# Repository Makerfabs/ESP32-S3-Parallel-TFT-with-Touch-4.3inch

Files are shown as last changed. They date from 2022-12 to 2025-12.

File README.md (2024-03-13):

# Makerfabs ESP32-S3 Parallel TFT with Touch 4.3inch

```c++
/*
Version:        V1.1
Author:            Vincent
Create Date:    2022/12/29
Note:
    2023/4/15 V1.2: Update V2.0 hardware.
    2023/1/10 V1.1: Update code to match the V1.3 hardware.
*/
```

[TOC]

# Makerfabs

[Makerfabs home page](https://www.makerfabs.com/)

[Makerfabs Wiki](https://wiki.makerfabs.com/)

# Makerfabs ESP32-S3 Parallel TFT with Touch 4.3inch

## Intruduce

Product Link ：[ESP32-S3 Parallel TFT with Touch 4.3"](https://www.makerfabs.com/esp32-s3-parallel-tft-with-touch-4-3-inch.html)

Wiki Link : [ESP32-S3 Parallel 4.3 TFT with Touch](http://wiki.makerfabs.com/ESP32_S3_Parallel_4.3_TFT_with_Touch.html)

This ESP32 4.3 inch IPS display could be an ideal displayer& controller for IoT applications. Its high lightness IPS display with a resolution of 800*480 makes the display effect beautiful, together with 5 points capacitive touch, great for applications such as home automation; There onboard SD card and RTC, to make it possible to record/play filed data. Also, there 2 Mabee/ Grove connectors, so the users can connect kinds of sensors to this board, to create personal prototype projects instantly.

The ESP32-S3 has WiFi& Bluetooth 5.0, and 8M PSRAM ESP32-S3 is used in this product, with 16M flash, to make it competent for more advanced applications.

## Feature

- Controller: ESP32-S3-WROOM-1, PCB Antenna, 16MB Flash, 8MB PSRAM, ESP32-S3-WROOM-1-N16R8
- On Board RTC
- Wireless: Wifi& Bluetooth 5.0
- LCD: 4.3 inch High Lightness IPS
- FPS: >30
- Resolution: 800*480
- LCD interface: RGB 565
- Touch Panel: 5 Points Touch, Capacitive
- Touch Panel Driver: GT911
- USB: Dual USB Type-C(one for USB-to-UART and one for native USB)
- USB to UART Chip: CP2104
- Power Supply: USB Type-C 5.0V(4.0V~5.25V)
- Button: Flash button and reset button
- Mabee interface: 1*I2C;1*GPIO
- MicroSD: Yes
- Arduino support: Yes
- Type-C Power Delivery: Not Supported
- Operation temperature: -40℃ to +85℃

## Version Attention

### V2.0

The codes has not been modified yet, please wait a little.

Still working...

| | V2.0 | V1.3 |
| --- | ---- | ---- |
| LCD_BLK | NULL | 2 |
| I2S_DIN | 19 | NULL |
| I2S_BCLK  | 20 | NULL |
| I2S_LRCLK | 2 | NULL |
| | | |

Now the screen has no backlight PWM adjustment function, the pins are assigned to I2S. By default, the hardware backlight is always on.

### V1.3

V1.3 switches the touch screen RST and INT pins compared to V1.1 hardware.

```c++
// Hardware V1.3
#define TOUCH_GT911_SCL 18
#define TOUCH_GT911_SDA 17
#define TOUCH_GT911_INT -1
#define TOUCH_GT911_RST 38
```

### V1.1

If the silk screen on the back of your hardware is V1.1, follow the Branch V1.1 procedure.

# Code

## Complier Option

- Install board : ESP32 (Version 2.0.4)
- Install libraries：

library

- Use type-c use cable connect USB-TTL to PC.
- Select "ESP32-S3 DEV Module"
- Select PSRAM "OPI PSRAM"

"mf_Lvgl" library is modified from Lvgl library (version 8.3.2). 

Please unzip "lib/mf_Lvgl.zip" and copy to arduino library directory.

## Factory test program

examples\esp32s3_4.3_tft_fw_test

You can run this file test if you feel that your hardware is not working properly. You need to copy the images from the Images folder to the included TF card.

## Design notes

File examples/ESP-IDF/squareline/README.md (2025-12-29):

## LVGL design with SquareLine Studio

1. Click on Squareline to log in to your account, or click on "Sign up" if you don't have one.

2. Create a project.

2. Design Interface.

3. Export the UI code and select a folder to save it to.

   

## Code Upload with IDF

- Clone the [ESP32-S3-Parallel-TFT-with-Touch-4.3inch](https://github.com/Makerfabs/ESP32-S3-Parallel-TFT-with-Touch-4.3inch/tree/main) repository and configure it according to the documentation.

  ```bash
  git clone https://github.com/Makerfabs/ESP32-S3-Parallel-TFT-with-Touch-4.3inch.git
  ```

- Copy the previously exported `ui` folder to the `components` directory and modify `ui/CmakeLists.txt`.

  > This example uses an interface I designed as an illustration.

  ```cmake
  idf_component_register(
      SRCS 
          "ui.c"
          "ui_helpers.c"
          "components/ui_comp.c"
          "components/ui_comp_card.c"
          "components/ui_comp_hook.c"
          "screens/ui_Screen1.c"
          "images/ui_img_wifi_png.c"
          "images/ui_img_home_png.c"
          "images/ui_img_1292609536.c"
          "images/ui_img_image_png.c"
          "images/ui_img_music_png.c"
          "images/ui_img_bell_png.c"
          "images/ui_img_settings_png.c"
      INCLUDE_DIRS 
          "."
          "components" 
          "screens"
          "images"
      REQUIRES 
          lvgl
  )
  ```

- Include the UI header file in `main/firmware/template.c`.

  ```c
  #include "ui.h"
  ```

  Modify the `template_lvgl_demos_test` function.

  ```c
  void template_lvgl_demos_test()
  {
      lvgl_port_lock(0);
  
      // lv_demo_widgets();
      
      // ui_init_styles();
      // create_main_ui();
  
      ui_init();
  
      lvgl_port_unlock();
  }
  ```

- Modify `main/release/4-3-unknown-gt911/release.c`

  ```c
  static void release_task(void *arg)
  {
      // extern void template_image_switch_lvgl(const char *path);
      // template_image_switch_lvgl("/sdcard/images");
  
      extern void template_lvgl_demos_test();
      template_lvgl_demos_test();
  
      // extern void template_dht11_test();
      // template_dht11_test();
  
      // extern void template_mpu6050_test();
      // template_mpu6050_test();
      
      vTaskDelete(NULL);
  }
  ```

After compiling and flashing the code at this stage, you should be able to see the interface designed in **Squareline Studio** on the screen.  Next, we will connect the **MPU6050** to the development board and display the sensor data on the designed interface.

- Add the **mpu6050** component. Modify `main/idf_components.yml` and add the following at the end:

  ```yml
  k0i05/esp_mpu6050: 1.2.7
  ```

- Modify `main/boards/board.h` and add the following at the end:

  ```c
  extern i2c_master_bus_handle_t _i2c_bus;
  ```

- The **MPU6050** sensor is connected to the **J2** interface on the development board. Modify the `main/firmware/template.c` file and add the `template_mpu6050_test` function.

  ```c
  void template_mpu6050_test()
  {
      mpu6050_config_t dev_cfg          = I2C_MPU6050_CONFIG_DEFAULT;
      dev_cfg.accel_full_scale_range    = MPU6050_ACCEL_FS_RANGE_2G;
      mpu6050_handle_t dev_hdl;
      //
      // init device
      mpu6050_init(_i2c_bus, &dev_cfg, &dev_hdl);
  
      uint8_t                                 sample_rate_divider_reg;
      mpu6050_config_register_t               config_reg;
      mpu6050_gyro_config_register_t          gyro_config_reg;
      mpu6050_accel_config_register_t         accel_config_reg;
      mpu6050_interrupt_enable_register_t     irq_enable_reg;
      mpu6050_power_management1_register_t    power_management1_reg;
      mpu6050_power_management2_register_t    power_management2_reg;
      mpu6050_who_am_i_register_t             who_am_i_reg;
  
      /* attempt to read device sample rate divider register */
      mpu6050_get_sample_rate_divider_register(dev_hdl, &sample_rate_divider_reg);
  
      /* attempt to read device configuration register */
      mpu6050_get_config_register(dev_hdl, &config_reg);
  
      /* attempt to read device gyroscope configuration register */
      mpu6050_get_gyro_config_register(dev_hdl, &gyro_config_reg);
  
      /* attempt to read device accelerometer configuration register */
      mpu6050_get_accel_config_register(dev_hdl, &accel_config_reg);
  
      /* attempt to read device interrupt enable register */
      mpu6050_get_interrupt_enable_register(dev_hdl, &irq_enable_reg);
  
      /* attempt to read device power management 1 register */
      mpu6050_get_power_management1_register(dev_hdl, &power_management1_reg);
  
      /* attempt to read device power management 2 register */
      mpu6050_get_power_management2_register(dev_hdl, &power_management2_reg);
  
      /* attempt to read device who am i register */
      mpu6050_get_who_am_i_register(dev_hdl, &who_am_i_reg);
  
          // show registers
      ESP_LOGI(TAG, "Sample Rate Divider Register:         0x%02x (%s)", sample_rate_divider_reg, uint8_to_binary(sample_rate_divider_reg));
      ESP_LOGI(TAG, "Configuration Register:               0x%02x (%s)", config_reg.reg, uint8_to_binary(config_reg.reg));
      ESP_LOGI(TAG, "Gyroscope Configuration Register:     0x%02x (%s)", gyro_config_reg.reg, uint8_to_binary(gyro_config_reg.reg));
      ESP_LOGI(TAG, "Accelerometer Configuration Register: 0x%02x (%s)", accel_config_reg.reg, uint8_to_binary(accel_config_reg.reg));
      ESP_LOGI(TAG, "Interrupt Enable Register:            0x%02x (%s)", irq_enable_reg.reg, uint8_to_binary(irq_enable_reg.reg));
      ESP_LOGI(TAG, "Power Management 1 Register:          0x%02x (%s)", power_management1_reg.reg, uint8_to_binary(power_management1_reg.reg));
      ESP_LOGI(TAG, "Power Management 2 Register:          0x%02x (%s)", power_management2_reg.reg, uint8_to_binary(power_management2_reg.reg));
      ESP_LOGI(TAG, "Who am I Register:                    0x%02x (%s)", who_am_i_reg.reg, uint8_to_binary(who_am_i_reg.reg));
  
      while (1) {
          // handle sensor
          float temperature;
          mpu6050_gyro_data_axes_t gyro_data;
          mpu6050_accel_data_axes_t accel_data;
          esp_err_t result = mpu6050_get_motion(dev_hdl, &gyro_data, &accel_data, &temperature);
          if(result != ESP_OK) {
              ESP_LOGE(TAG, "mpu6050 device read failed (%s)", esp_err_to_name(result));
          } else {
              /* pitch and roll */
              float pitch = atanf(accel_data.x_axis / sqrtf(powf(accel_data.y_axis, 2.0f) + powf(accel_data.z_axis, 2.0f)));
              float roll  = atanf(accel_data.y_axis / sqrtf(powf(accel_data.x_axis, 2.0f) + powf(accel_data.z_axis, 2.0f)));
  
              // ESP_LOGI(TAG, "Accelerometer X-Axis: %fg", accel_data.x_axis);
              // ESP_LOGI(TAG, "Accelerometer Y-Axis: %fg", accel_data.y_axis);
              // ESP_LOGI(TAG, "Accelerometer Z-Axis: %fg", accel_data.z_axis);
              // ESP_LOGI(TAG, "Gyroscope X-Axis:     %f°/sec", gyro_data.x_axis);
              // ESP_LOGI(TAG, "Gyroscope Y-Axis:     %f°/sec", gyro_data.y_axis);
              // ESP_LOGI(TAG, "Gyroscope Z-Axis:     %f°/sec", gyro_data.z_axis);
              // ESP_LOGI(TAG, "Temperature:          %f°C", temperature);
              // ESP_LOGI(TAG, "Pitch Angle:          %f°", pitch);
              // ESP_LOGI(TAG, "Roll Angle:           %f°", roll);
  
              lvgl_port_lock(0);
              lv_obj_t * label_temp = ui_comp_get_child(ui_card, UI_COMP_CARD_LBLTEMP);
              lv_obj_t * label_accel_x = ui_comp_get_child(ui_card1, UI_COMP_CARD_LBLTEMP);
              lv_obj_t * label_accel_y = ui_comp_get_child(ui_card2, UI_COMP_CARD_LBLTEMP);
              lv_obj_t * label_accel_z = ui_comp_get_child(ui_card3, UI_COMP_CARD_LBLTEMP);
              lv_label_set_text_fmt(label_temp, "%d", (int)temperature);
              lv_label_set_text_fmt(label_accel_x, "%.2f", accel_data.x_axis);
              lv_label_set_text_fmt(label_accel_y, "%.2f", accel_data.y_axis);
              lv_label_set_text_fmt(label_accel_z, "%.2f", accel_data.z_axis);
              lvgl_port_unlock();

          }
          vTaskDelay(pdMS_TO_TICKS(1000));
      }
  }
  ```

- Modify `main/release/4-3-unknown-gt911/release.c`

  ```c
  static void release_task(void *arg)
  {
      // extern void template_image_switch_lvgl(const char *path);
      // template_image_switch_lvgl("/sdcard/images");
  
      extern void template_lvgl_demos_test();
      template_lvgl_demos_test();
  
      // extern void template_dht11_test();
      // template_dht11_test();
  
      extern void template_mpu6050_test();
      template_mpu6050_test();
      
      vTaskDelete(NULL);
  }
  ```

- The compilation, flashing, and execution results are as follows:

  VID20251229143917-ezgif.com-optimize

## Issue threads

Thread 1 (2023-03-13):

Arduino IDE 2.0.x

WanaGo, 2023-03-13:
Hi,
Have you attempted to get the LVGL Benchmark to compile and build using the Arduino 2.0.x IDE, rather than the 1.8.x IDE?

I cant get it to compile, just get weird errors which dont really say much.

```
Using library lvgl at version 8.3.2 in folder: C:\Users\wanago\Documents\Arduino\libraries\mf_Lvgl 
Using library GFX Library for Arduino at version 1.3.2 in folder: C:\Users\wanago\Documents\Arduino\libraries\GFX_Library_for_Arduino 
Using library SPI at version 2.0.0 in folder: C:\Users\wanago\AppData\Local\Arduino15\packages\esp32\hardware\esp32\2.0.7\libraries\SPI 
Using library Wire at version 2.0.0 in folder: C:\Users\wanago\AppData\Local\Arduino15\packages\esp32\hardware\esp32\2.0.7\libraries\Wire
```

```
c:/users/wanago/appdata/local/arduino15/packages/esp32/tools/xtensa-esp32s3-elf-gcc/esp-2021r2-patch5-8.4.0/bin/../lib/gcc/xtensa-esp32s3-elf/8.4.0/../../../../xtensa-esp32s3-elf/bin/ld.exe: C:\Users\wanago\AppData\Local\Temp\arduino\sketches\94789ED864D1E8CA07644E860EFAA592\sketch\objs.a(LvglBenchmark.ino.cpp.o):(.literal._Z5setupv+0x48): undefined reference to `lv_demo_benchmark'
c:/users/wanago/appdata/local/arduino15/packages/esp32/tools/xtensa-esp32s3-elf-gcc/esp-2021r2-patch5-8.4.0/bin/../lib/gcc/xtensa-esp32s3-elf/8.4.0/../../../../xtensa-esp32s3-elf/bin/ld.exe: C:\Users\wanago\AppData\Local\Temp\arduino\sketches\94789ED864D1E8CA07644E860EFAA592\sketch\objs.a(LvglBenchmark.ino.cpp.o): in function `setup()':
C:\Users\wanago\AppData\Local\Temp\.arduinoIDE-unsaved2023214-6888-1djzjol.71qj\LvglBenchmark/LvglBenchmark.ino:168: undefined reference to `lv_demo_benchmark'
collect2.exe: error: ld returned 1 exit status exit status 1 Compilation error: exit status 1
```

I see there is LVGL 8.3.5 available now, but given this uses a modified version of that 8.3.2 library I cannot upgrade to that to try it.

Any suggestions?

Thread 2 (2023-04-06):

hardware version 2.0

charnwooduk, 2023-04-06:
I received my board, but the silkscreen states it is version 2.0.

I appear to get the following error when using gfx library with the following settings : -

(using gfx version 1.3.1)

`
#include <Arduino_GFX_Library.h>
#define GFX_BL 2
#define TFT_BL GFX_BL
Arduino_ESP32RGBPanel *bus = new Arduino_ESP32RGBPanel(
    GFX_NOT_DEFINED /* CS */, GFX_NOT_DEFINED /* SCK */, GFX_NOT_DEFINED /* SDA */,
    40 /* DE */, 41 /* VSYNC */, 39 /* HSYNC */, 42 /* PCLK */,
    45 /* R0 */, 48 /* R1 */, 47 /* R2 */, 21 /* R3 */, 14 /* R4 */,
    5 /* G0 */, 6 /* G1 */, 7 /* G2 */, 15 /* G3 */, 16 /* G4 */, 4 /* G5 */,
    8 /* B0 */, 3 /* B1 */, 46 /* B2 */, 9 /* B3 */, 1 /* B4 */
);

// Uncomment for ST7262 IPS LCD 800x480
 Arduino_RPi_DPI_RGBPanel *gfx = new Arduino_RPi_DPI_RGBPanel(
   bus,
   800 /* width */, 0 /* hsync_polarity */, 8 /* hsync_front_porch */, 4 /* hsync_pulse_width */, 8 /* hsync_back_porch */,
   480 /* height */, 0 /* vsync_polarity */, 8 /* vsync_front_porch */, 4 /* vsync_pulse_width */, 8 /* vsync_back_porch */,
   1 /* pclk_active_neg */, 16000000 /* prefer_speed */, true /* auto_flush */);
`

Error: -
`
E (10) lcd_panel.rgb: esp_lcd_new_rgb_panel(151): no mem for frame buffer
ESP_ERROR_CHECK failed: esp_err_t 0x101 (ESP_ERR_NO_MEM) at 0x4037abb0
file: "C:\Users\Documents\Arduino\libraries\GFX_Library_for_Arduino\src\databus\Arduino_ESP32RGBPanel.cpp" line 252
func: uint16_t* Arduino_ESP32RGBPanel::getFrameBuffer(uint16_t, uint16_t, uint16_t, uint16_t, uint16_t, uint16_t, uint16_t, uint16_t, uint16_t, uint16_t, uint16_t, int32_t)
expression: esp_lcd_new_rgb_panel(_panel_config, &_panel_handle)
abort() was called at PC 0x4037abb3 on core 1
Backtrace: 0x40377862:0x3fcebc00 0x4037abbd:0x3fcebc20 0x40380ed5:0x3fcebc40 0x4037abb3:0x3fcebcc0 0x4200299b:0x3fcebce0 0x42002a9b:0x3fcebd40 0x42001928:0x3fcebd80 0x420046ca:0x3fcebda0
ELF file SHA256: 97d90b6539d5a233
Rebooting...
`

charnwooduk, 2023-04-07:
my mistake, fixed by following the instructions and setting OPI PSRAM .

Closed 2023-04-07.

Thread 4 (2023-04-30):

Clock example error - Hardware v2

ayouboss, 2023-04-30:
Compilation error: no matching function for call to 'Arduino_ESP32RGBPanel::Arduino_ESP32RGBPanel(int, int, int, int, int, int, int, int, int, int, int, int, int, int, int, int, int, int, int, int, int, int, int)'

zingo, 2023-05-04:
It could be that you picked up a the wrong version GFX Library for Arduino when I set up my project I had to lock it to 1.3.1
see:
https://github.com/zingo/CrazyCapyTime/blob/main/platformio.ini

ayouboss, 2023-05-04:
Thanks I will try that. I'm wondering if the same issue happens for LovyanGFX example: https://github.com/Makerfabs/ESP32-S3-Parallel-TFT-with-Touch-4.3inch/tree/main/examples/LovyanGFX_demo

When I upload the sketch I once get a full white screen, once full red, green, and blue screens. I've checked the Pinout in the header file and it seems to be correct. Comments even mention hardware v2.0.

Thanks in advance.

vibr77, 2023-05-20:
Same here none of the exemple are working....
black screen for clock, random for LovyanGFX...

seijikun, 2024-02-28:
I was able to get the clock example to work with `Arduino GFX 1.4.5` by replacing the [init code](https://github.com/Makerfabs/ESP32-S3-Parallel-TFT-with-Touch-4.3inch/blob/main/examples/Clock/Clock.ino#L10) with this:

```c++
Arduino_ESP32RGBPanel *bus = new Arduino_ESP32RGBPanel(
    40 /* DE */, 41 /* VSYNC */, 39 /* HSYNC */, 42 /* PCLK */,
    45 /* R0 */, 48 /* R1 */, 47 /* R2 */, 21 /* R3 */, 14 /* R4 */,
    5 /* G0 */, 6 /* G1 */, 7 /* G2 */, 15 /* G3 */, 16 /* G4 */, 4 /* G5 */,
    8 /* B0 */, 3 /* B1 */, 46 /* B2 */, 9 /* B3 */, 1 /* B4 */,
    0 /* hsync_polarity */, 8 /* hsync_front_porch */, 4 /* hsync_pulse_width */, 8 /* hsync_back_porch */,
    0 /* vsync_polarity */, 8 /* vsync_front_porch */, 4 /* vsync_pulse_width */, 8 /* vsync_back_porch */,
    1 /* pclk_active_neg */, 16000000 /* prefer_speed */, false, 0, 0
);
Arduino_RGB_Display* gfx = new Arduino_RGB_Display(800, 480, bus, 0, true, nullptr, GFX_NOT_DEFINED, nullptr, GFX_NOT_DEFINED, 0, 0, 0, 0);
```

sukesh-ak, 2024-02-29:
Here is a simple example for the device using `LovyanGFX` to get you started.
https://gist.github.com/sukesh-ak/c8325c4bb7ec3da40f24977526d513f8

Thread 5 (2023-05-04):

Add debugging to the guide

zingo, 2023-05-04:
It would be nice to add a guide on the README.md or other place on how to setup debugging via the onboard USB-JTAG stuff added in ESP32-S3 preferable with PlatformIO or any other means.  Been struggling with this for a few hours now without to much luck :)

GroundLevel1, 2023-05-05:
Hello
   Debugging tools are great in assistance of programing errors/issues,
they will always be welcomed.

Bryan H

On Thu, May 4, 2023 at 6:53 AM Zingo Andersen ***@***.***>
wrote:

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

zingo, 2023-06-01:
Experiemented some more it seem to show up on the USB-NATIVE connection if you press RST and FLASH at the same time.

`
zingo@zingodatan:~$ lsusb
...
Bus 002 Device 016: ID 303a:1001 Espressif USB JTAG/serial debug unit
...

zingo@zingodatan:~$ openocd -f board/esp32s3-builtin.cfg
Open On-Chip Debugger v0.11.0-esp32-20221026 (2022-10-26-14:47)
Licensed under GNU GPL v2
For bug reports, read
	http://openocd.org/doc/doxygen/bugs.html
Info : only one transport option; autoselect 'jtag'
Info : esp_usb_jtag: VID set to 0x303a and PID to 0x1001
Info : esp_usb_jtag: capabilities descriptor set to 0x2000
Warn : Transport "jtag" was already selected
Info : Listening on port 6666 for tcl connections
Info : Listening on port 4444 for telnet connections
Info : esp_usb_jtag: serial (34:85:18:98:52:3C)
Info : esp_usb_jtag: Device found. Base speed 40000KHz, div range 1 to 255
Info : clock speed 40000 kHz
Info : JTAG tap: esp32s3.cpu0 tap/device found: 0x120034e5 (mfg: 0x272 (Tensilica), part: 0x2003, ver: 0x1)
Info : JTAG tap: esp32s3.cpu1 tap/device found: 0x120034e5 (mfg: 0x272 (Tensilica), part: 0x2003, ver: 0x1)
Error: [esp32s3.cpu1] Unexpected OCD_ID = 00000000
Warn : target esp32s3.cpu1 examination failed
Info : starting gdb server for esp32s3.cpu0 on 3333
Info : Listening on port 3333 for gdb connections
Info : [esp32s3.cpu0] Debug controller was reset.
Info : [esp32s3.cpu0] Core was reset.
Info : [esp32s3.cpu0] Target halted, PC=0x40041A76, debug_reason=00000000
Info : [esp32s3.cpu0] Reset cause (1) - (Power on reset)
Error: [esp32s3.cpu1] Unexpected OCD_ID = 00000000
Error: [esp32s3.cpu1] Unexpected OCD_ID = 00000000
Error: [esp32s3.cpu1] Unexpected OCD_ID = 00000000
Error: [esp32s3.cpu1] Unexpected OCD_ID = 00000000
Error: [esp32s3.cpu1] Unexpected OCD_ID = 00000000

`

zingo, 2023-10-06:
started to play with this again, got some more to work:

1. Setup platformIO

`
platform = espressif32
board = esp32s3box
;board = esp32-s3-devkitc-1
board_build.filesystem = littlefs
;board_build.mcu = esp32s3
;board_build.f_cpu = 240000000L
framework = arduino
build_type = debug
debug_tool = esp-builtin
debug_init_break = tbreak initRaceDB
;upload_protocol = esp-builtin
upload_protocol = esptool
upload_speed = 921600
`

2. Experiemented some more it seem to show up on the USB-NATIVE connection if you press RST and FLASH at the same time.

3. in PlatformIO go to debug and select "PIO Debug"
check that it connects ok in "DEBUG CONSOLE"

4.  Press "RST" button, it seem to restart and contnue to the code and stop there

I had a breakpoint at start of setup() and it seem to get stuck there so this is not 100% working but seem to be roughtly the way to go :)

zingo, 2023-10-06:
It seem to work as it should with the settings above move code probed different deb boards by checking if there was a i2c touch controller on pin 19,20 this is the same pins as USB-Native uses so if this code had executed it didn't work so the error was on my side. It works with the the platformIO setting above it you don't touch pin 19,20 I close this.

Closed 2023-10-06.

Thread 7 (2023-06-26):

None of the Examples worked

RedStarITA, 2023-06-26:
I've tried every examples possible with my "ESP32-S3 Parallele TFT with Touch 4.3 V3.1", and it keeps saying:
"Compilation error: 'Arduino_ESP32RGBPanel' does not name a type; did you mean 'Arduino_ESP32SPI'?"

What's the problem? Is it about the libraries or what?

sukesh-ak, 2023-06-27:
@RedStarITA
You can try this sample and check
https://gist.github.com/sukesh-ak/c8325c4bb7ec3da40f24977526d513f8

barnbrooksystems, 2023-07-28:
Thanks @sukesh-ak at least your example works.  Rubbish support from the manufacturer

arcanine84, 2023-11-10:
Your example no longer works for the V3.1.

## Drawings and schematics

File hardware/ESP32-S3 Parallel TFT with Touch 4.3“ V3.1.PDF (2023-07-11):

POWER | USB to UART

# LCD

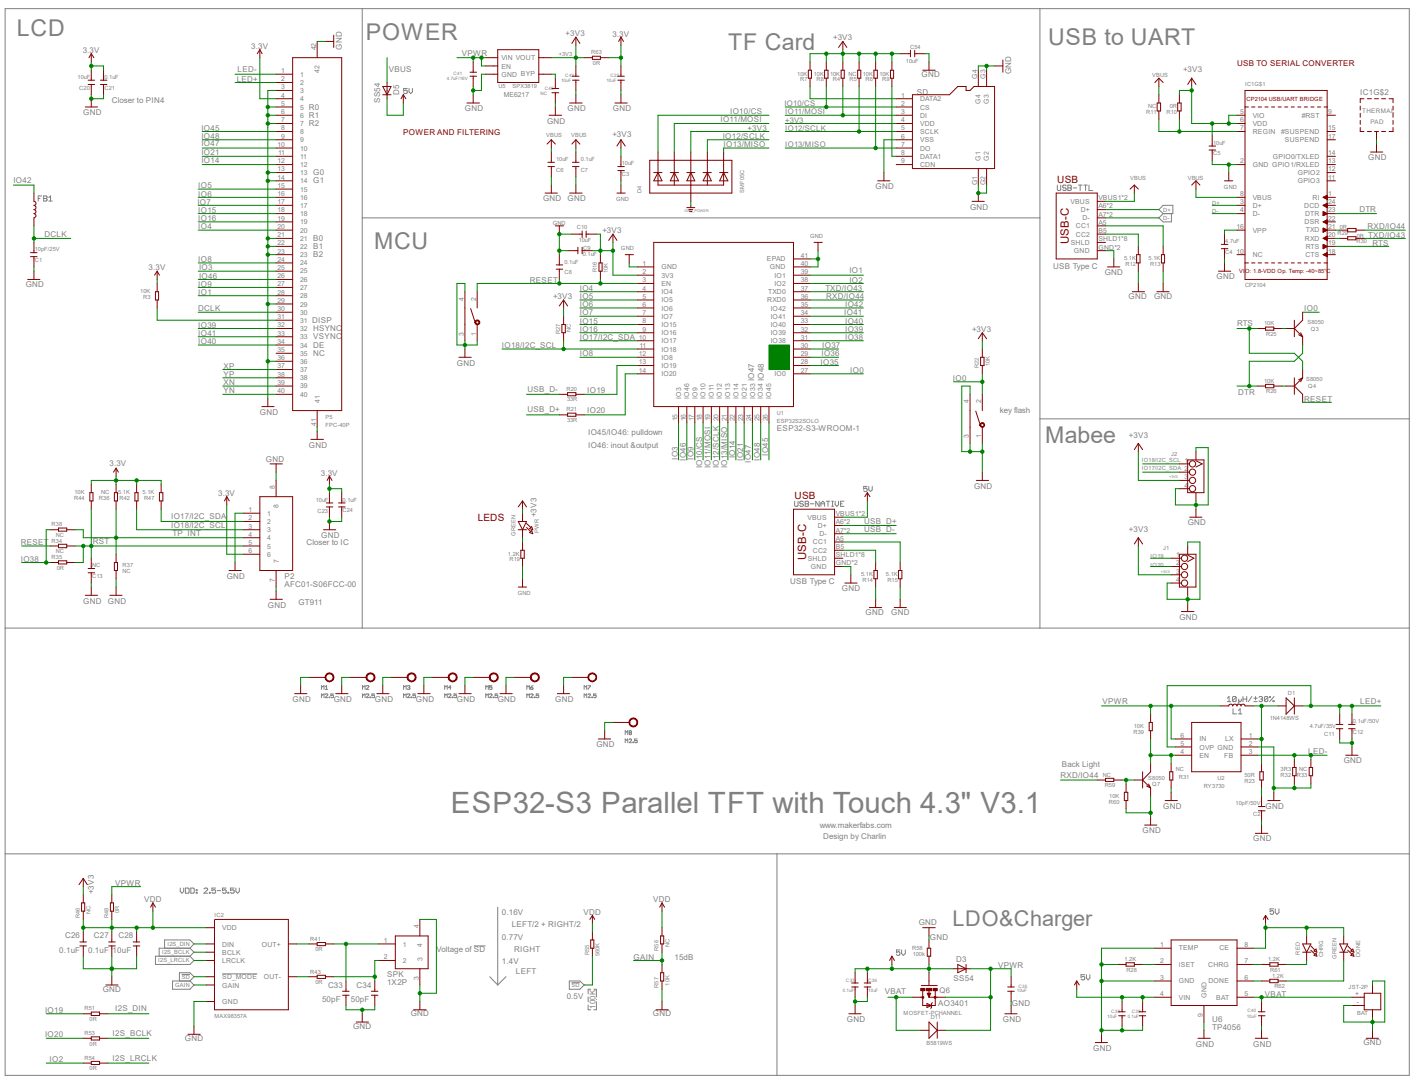
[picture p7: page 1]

USB Type C TF Card

USB TO SERIAL CONVERTER

VIO: 1.8-VDD Op. Temp: -40~85°C USB⁻C USB⁻C

IO17/I2C_SDA | 1 2

ESP32-S3 Parallel TFT with Touch 4.3" V3.1

www.makerfabs.com Design by Charlin

VPWR VDD VDD | GND B5819WS

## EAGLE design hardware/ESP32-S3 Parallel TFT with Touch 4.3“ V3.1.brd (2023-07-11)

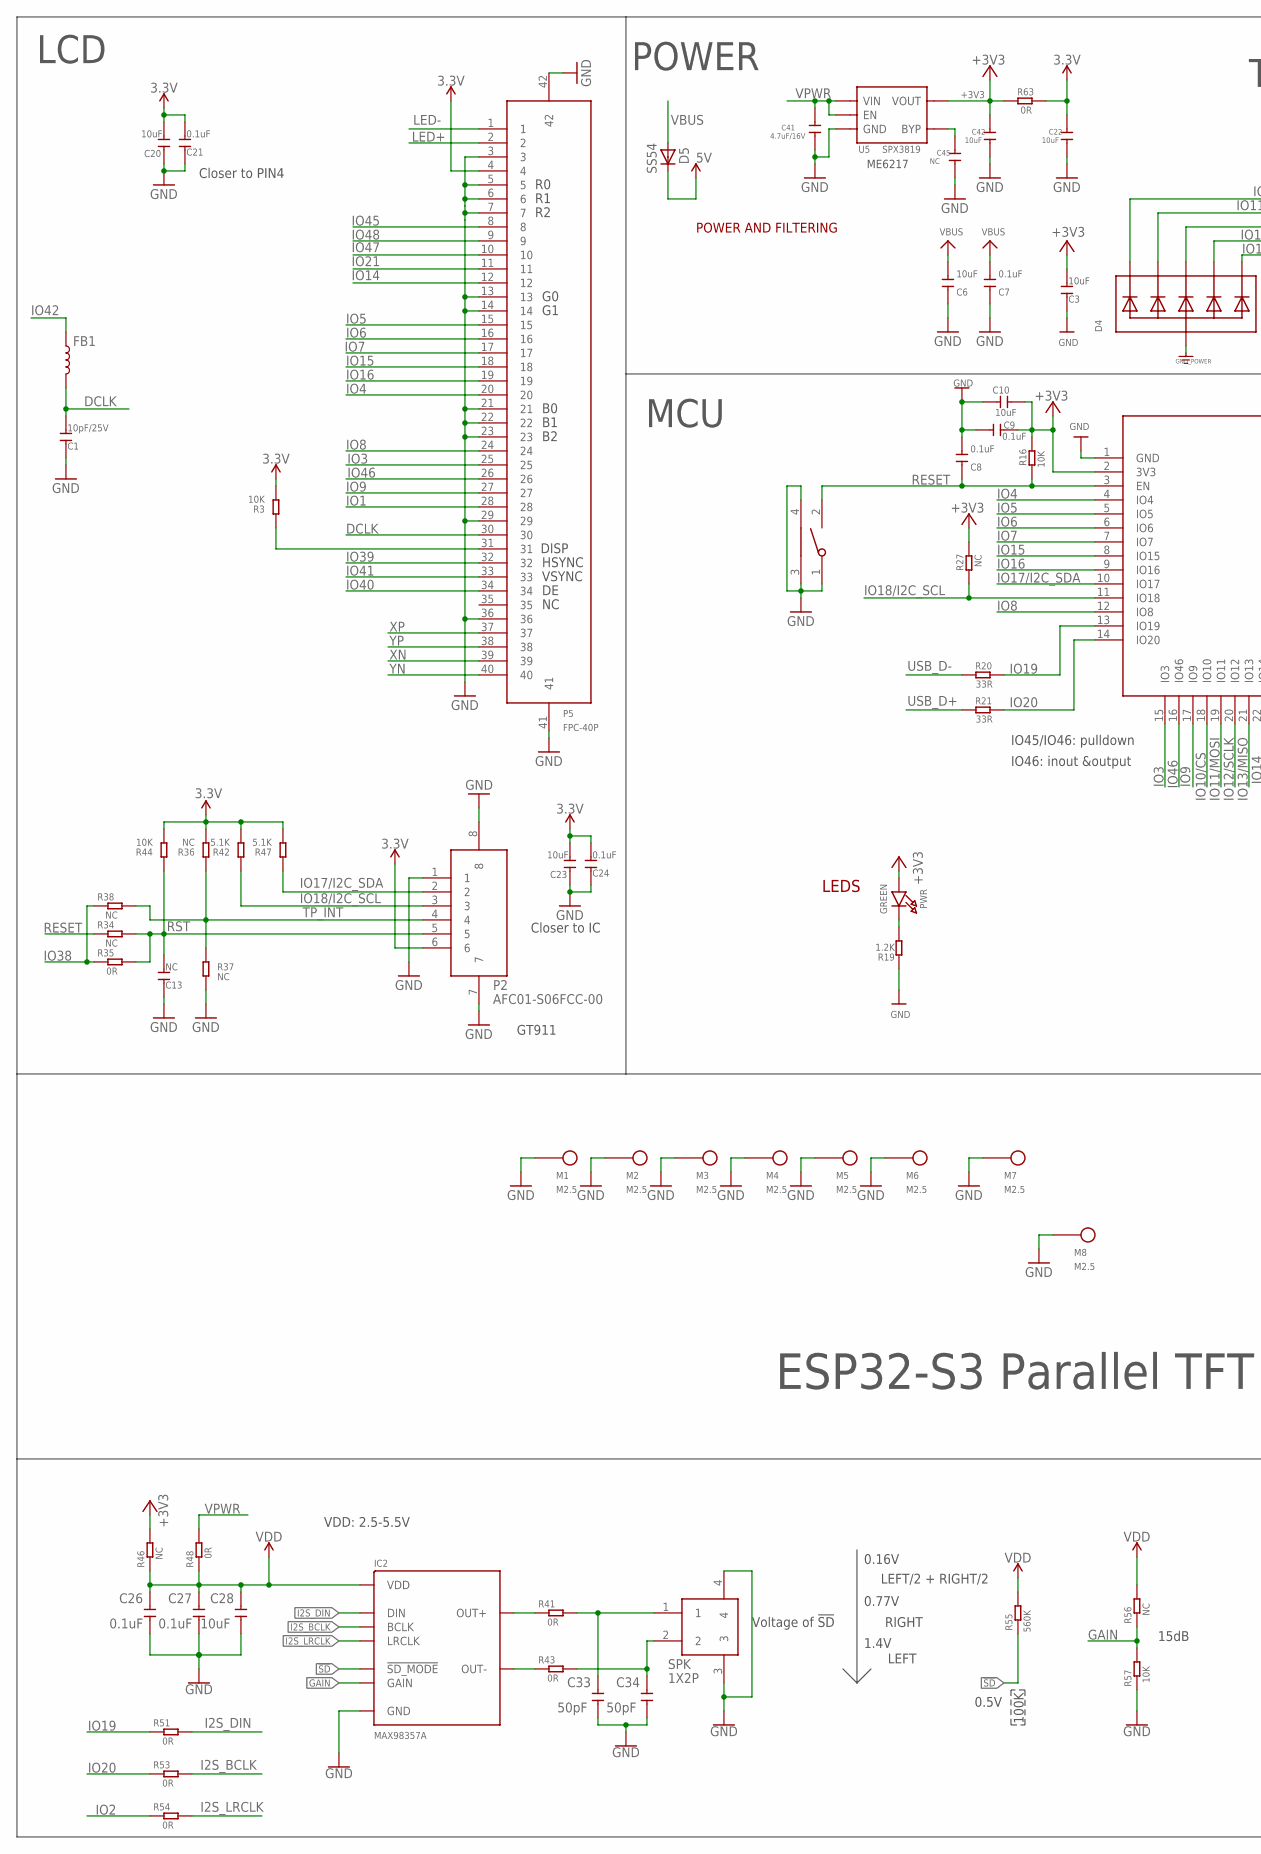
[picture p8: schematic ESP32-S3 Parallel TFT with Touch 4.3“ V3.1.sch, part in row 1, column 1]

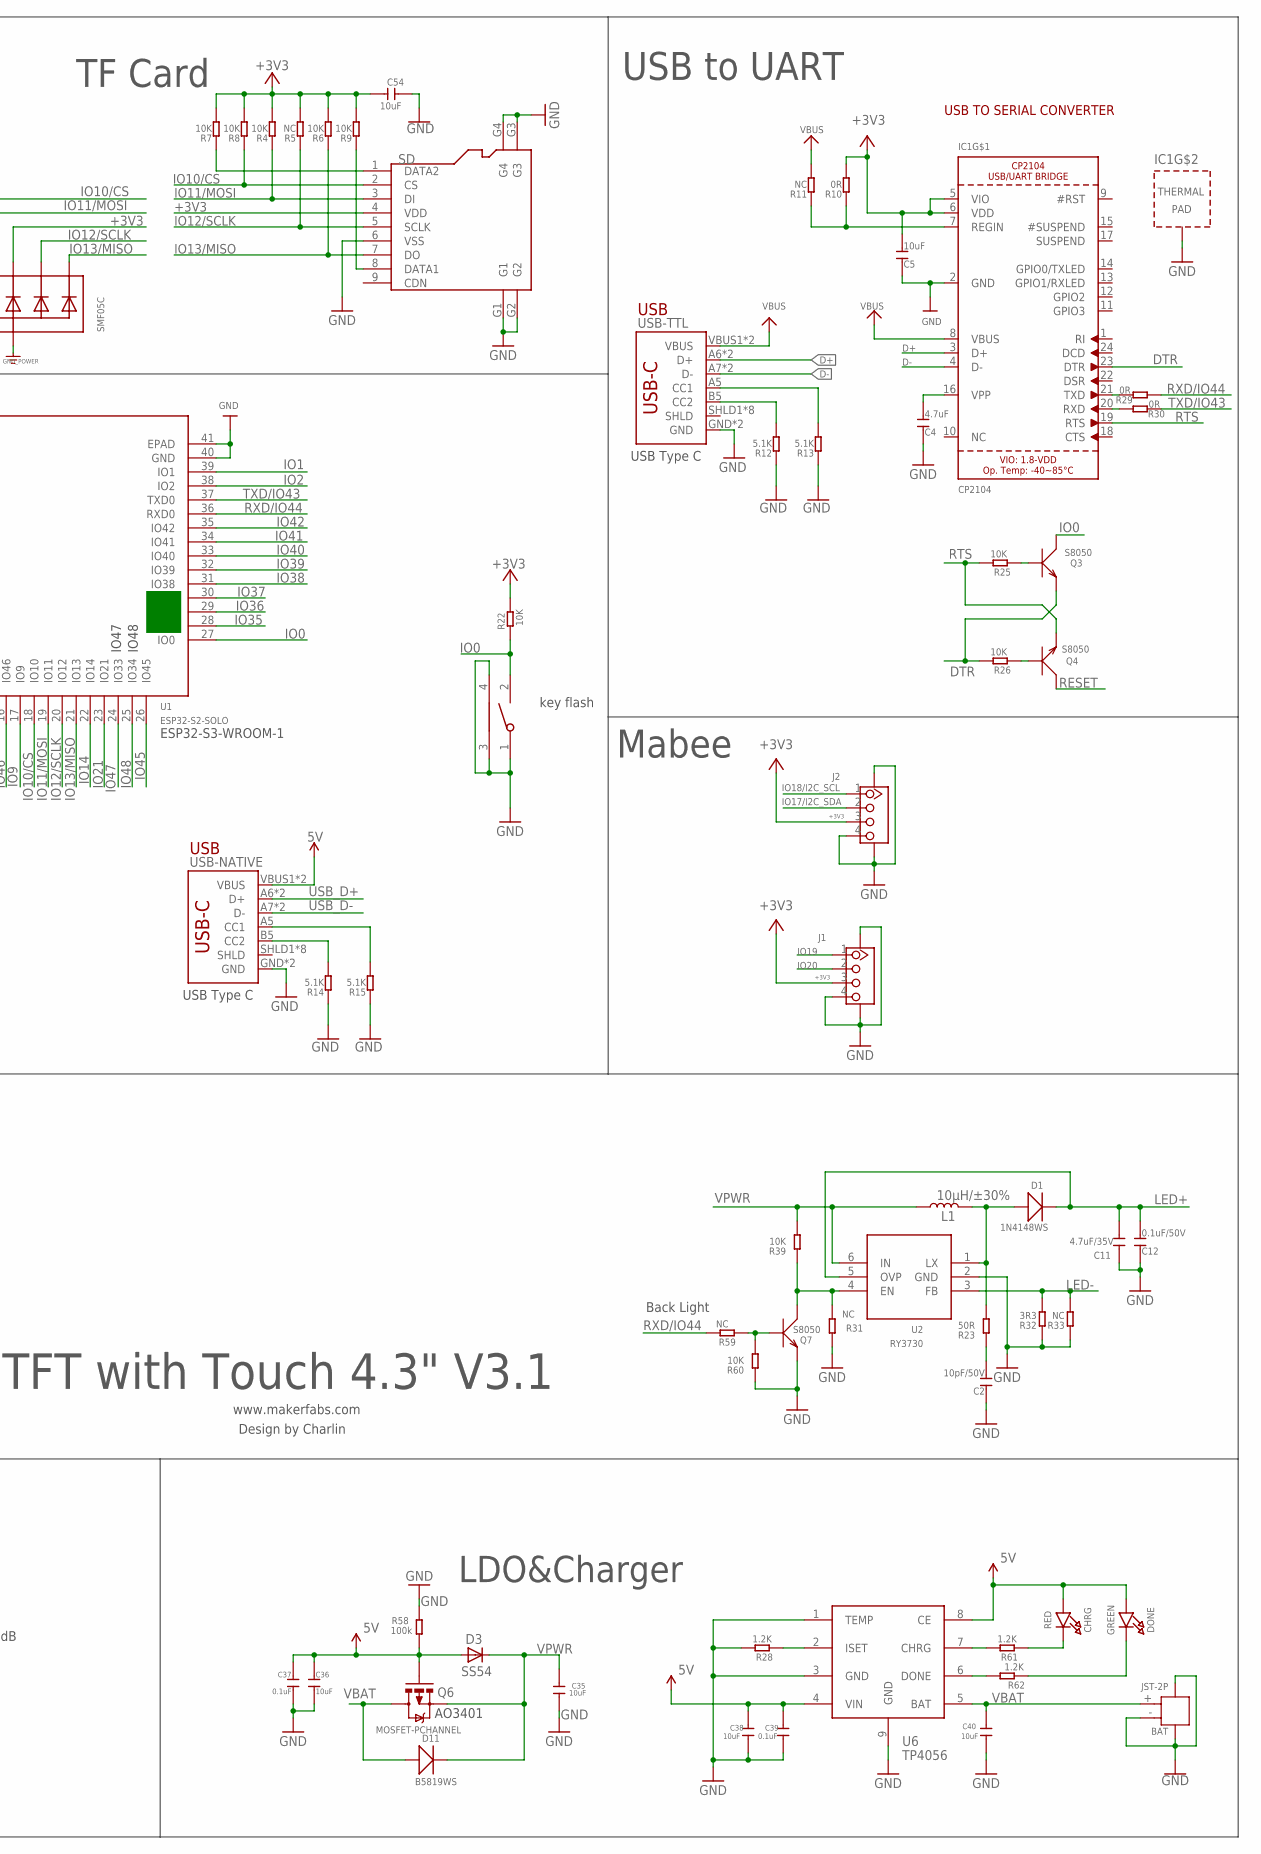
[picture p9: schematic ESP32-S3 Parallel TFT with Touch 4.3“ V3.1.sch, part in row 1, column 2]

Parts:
BAT: JST-2P; HW2-SMD-2.0-90D
BOOT: TS24CA; 2*4*3.5MM
C1: 10pF/25V; DISCRETE_C0603
C2: 10pF/50V; DISCRETE_C0603
C3, C5, C6, C10, C20, C23, C54: 10uF; DISCRETE_C0603
C4: 4.7uF; DISCRETE_C0603
C7, C8, C9, C21, C24: 0.1uF; DISCRETE_C0603
C11: 4.7uF/35V; DISCRETE_C1206
C12: 0.1uF/50V; DISCRETE_C0603
C13: NC; DISCRETE_C0603
C22, C28, C35, C36, C38, C40, C42: 10uF; 0603
C26, C27, C37, C39: 0.1uF; 0603
C33, C34: 50pF; 0603
C41: 4.7uF/16V; 0603
C45: NC; 0603
CHRG: RED; CHIPLED_0805_NOOUTLINE
D1: 1N4148WS; SOD323
D3, D5: SS54; DO-214AC
D4: SMF05C; SOT363
D11: B5819WS; SOD323
DONE: GREEN; CHIPLED_0805_NOOUTLINE
FB1: INDUCTORFB-30OHM; 0603
IC1: CP2104; QFN24_4MM_SMSC
IC2: MAX98357A; TQFN-16
J1, J2: GROVE-CONNECTOR-SMD'90D'; HW4-SMD-2.0-90D
L1: 10µH/±30%; CR54
M1, M2, M3, M4, M5, M6, M7, M8: M2.5
P2: AFC01-S06FCC-00; SMD8-50P-740L535W
P5: FPC-40P; SMD42-50P-2560L490W
PWR: GREEN; CHIPLED_0805_NOOUTLINE
Q3, Q4, Q7: S8050; SOT23
Q6: MOSFET-PCHANNEL; SOT23-3
R3, R4, R6, R7, R8, R9, R39, R44, R60: 10K; DISCRETE_R0603
R5, R11, R31, R33, R36, R37, R59: NC; DISCRETE_R0603
R10: 0R; DISCRETE_R0603
R12, R13, R14, R15, R42, R47: 5.1K; DISCRETE_R0603
R16, R22, R25, R26, R57: 10K; R0603
R19: 1.2K; DISCRETE_R0603
R20, R21: 33R; R0603
R23: 50R; DISCRETE_R0603
R27, R34, R38, R46, R56: NC; R0603
R28, R61, R62: 1.2K; R0603
R29, R30, R35, R41, R43, R48, R51, R53, R54, R63: 0R; R0603
R32: 3R3; DISCRETE_R0603
R55: 560K; R0603
R58: 100k; R0603
RST: TS24CA; 2*4*3.5MM
SD: HOLDER-MICROSD-9P; 9P-SMD-W/-RING
SPK: 1X2P; 1X2P-SMT1.25MM
U1: ESP32­S2­SOLO; ESP32-­S2-­SOLO
U2: RY3730; SOT23-6
U5: SPX3819; SOT23-5
U6: TP4056; SOP8-1.27P
USB-NATIVE: USB_C5; USB-C-16P-5
USB-TTL: USB_C5; USB-C-16P-5

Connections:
3.3V: C20.2, C21.2, C22.1, C23.2, C24.2, P2.6, P5.4, R3.2, R36.2, R42.2, R44.2, R47.2, R63.2
5V: C36.2, C37.1, C38.1, C39.1, CHRG.A, D3.A, D5.C, DONE.A, Q6.1 (G), R58.1, U6.4 (VIN), U6.8 (CE), USB-NATIVE.VBUS1 (VBUS), USB-NATIVE.VBUS2 (VBUS)
!SD: IC2.P$4 (!SD_MODE), R55.1
+3V3: C3.2, C5.2, C9.1, C10.1, C42.1, C54.2, D4.4 (C3), IC1.5 (VIO), IC1.6 (VDD), J1.3, J2.3, PWR.A, R4.2, R5.2, R6.2, R7.2, R8.2, R9.2, R10.2, R16.2, R22.2, R27.2, R46.2, R63.1, SD.4 (VDD), U1.2 (3V3), U5.5 (VOUT)
D+: IC1.3 (D+), USB-TTL.A6 (D+), USB-TTL.B6 (D+)
D-: IC1.4 (D-), USB-TTL.A7 (D-), USB-TTL.B7 (D-)
DCLK: C1.2, FB1.2, P5.30
DTR: IC1.23 (DTR), Q3.2 (E), R26.2
GAIN: IC2.P$2 (GAIN), R56.1, R57.2
GND: BAT.3, BAT.4, BAT.- (2), BOOT.1, BOOT.3, BOOT.4, C1.1, C2.1, C3.1, C4.1, C5.1, C6.1, C7.1, C8.2, C9.2, C10.2, C11.1, C12.1, C13.1, C20.1, C21.1, C22.2, C23.1, C24.1, C26.1, C27.1, C28.1, C33.1, C34.1, C35.1, C36.1, C37.2, C38.2, C39.2, C40.2, C41.2, C42.2, C45.2, C54.1, D4.2 (A), IC1.2 (GND), IC1.THERM (TP), IC2.P$3 (GND), IC2.P$11 (GND), IC2.P$15 (GND), IC2.P$EP (GND), J1.4, J1.SS1, J1.SS2, J2.4, J2.SS1, J2.SS2, M1.1, M2.1, M3.1, M4.1, M5.1, M6.1, M7.1, M8.1, P2.1, P2.7, P2.8, P5.3, P5.5, P5.6, P5.7, P5.13, P5.14, P5.21, P5.22, P5.23, P5.29, P5.36, P5.41, P5.42, Q7.2 (E), R12.1, R13.1, R14.1, R15.1, R19.1, R28.2, R31.1, R32.1, R33.1, R37.2, R57.1, R58.2, R60.1, RST.1, RST.3, RST.4, SD.6 (VSS), SD.G1, SD.G2, SD.G3, SD.G4, SPK.3, SPK.4, U1.1 (GND), U1.40 (GND), U1.41 (EPAD), U2.2 (GND), U5.2 (GND), U6.1 (TEMP), U6.3 (GND), U6.9 (GND), USB-NATIVE.GND, USB-NATIVE.GND2 (GND), USB-TTL.GND, USB-TTL.GND2 (GND)
I2S_BCLK: IC2.P$16 (BCLK), R53.2
I2S_DIN: IC2.P$1 (DIN), R51.2
I2S_LRCLK: IC2.P$14 (LRCLK), R54.2
IO0: BOOT.2, Q3.3 (C), R22.1, U1.27 (IO0)
IO1: P5.28, U1.39 (IO1)
IO2: R54.1, U1.38 (IO2)
IO3: P5.25, U1.15 (IO3)
IO4: P5.20, U1.4 (IO4)
IO5: P5.15, U1.5 (IO5)
IO6: P5.16, U1.6 (IO6)
IO7: P5.17, U1.7 (IO7)
IO8: P5.24, U1.12 (IO8)
IO9: P5.27, U1.17 (IO9)
IO10/CS: D4.1 (C1), R8.1, SD.2 (CS), U1.18 (IO10)
IO11/MOSI: D4.3 (C2), R4.1, SD.3 (DI), U1.19 (IO11)
IO12/SCLK: D4.5 (C4), R5.1, SD.5 (SCLK), U1.20 (IO12)
IO13/MISO: D4.6 (C5), R6.1, SD.7 (DO), U1.21 (IO13)
IO14: P5.12, U1.22 (IO14)
IO15: P5.18, U1.8 (IO15)
IO16: P5.19, U1.9 (IO16)
IO17/I2C_SDA: J2.2, P2.2, R47.1, U1.10 (IO17)
IO18/I2C_SCL: J2.1, P2.3, R27.1, R42.1, U1.11 (IO18)
IO19: J1.1, R20.2, R51.1, U1.13 (IO19)
IO20: J1.2, R21.2, R53.1, U1.14 (IO20)
IO21: P5.11, U1.23 (IO21)
IO35: U1.28 (IO35)
IO36: U1.29 (IO36)
IO37: U1.30 (IO37)
IO38: R35.1, R38.1, U1.31 (IO38)
IO39: P5.32, U1.32 (IO39)
IO40: P5.34, U1.33 (IO40)
IO41: P5.33, U1.34 (IO41)
IO42: FB1.1, U1.35 (IO42)
IO45: P5.8, U1.26 (IO45)
IO46: P5.26, U1.16 (IO46)
IO47: P5.10, U1.24 (IO33)
IO48: P5.9, U1.25 (IO34)
LED+: C11.2, C12.2, D1.-, P5.2, U2.5 (OVP)
LED-: P5.1, R32.2, R33.2, U2.3 (FB)
unnamed: C4.2, IC1.16 (VPP)
unnamed: Q4.1 (B), R26.1
unnamed: Q3.1 (B), R25.1
unnamed: R15.2, USB-NATIVE.A5 (CC1)
unnamed: PWR.C, R19.2
unnamed: R13.2, USB-TTL.A5 (CC1)
unnamed: R12.2, USB-TTL.B5 (CC2)
unnamed: IC1.7 (REGIN), R10.1, R11.1
unnamed: R14.2, USB-NATIVE.B5 (CC2)
unnamed: D1.+, L1.P$2 (2), R23.2, U2.1 (LX)
unnamed: IC1.21 (TXD), R29.2
unnamed: IC1.20 (RXD), R30.2
unnamed: IC2.P$9 (OUT+), R41.1
unnamed: C2.2, R23.1
unnamed: IC2.P$10 (OUT-), R43.1
unnamed: Q7.3 (C), R31.2, R39.1, U2.4 (EN)
unnamed: C33.2, R41.2, SPK.1
unnamed: C34.2, R43.2, SPK.2
unnamed: P5.31, R3.1
unnamed: Q7.1 (B), R59.1, R60.2
unnamed: R28.1, U6.2 (ISET)
unnamed: R61.2, U6.7 (CHRG)
unnamed: R62.2, U6.6 (DONE)
unnamed: CHRG.C, R61.1
unnamed: DONE.C, R62.1
unnamed: R7.1, SD.1 (DATA2)
unnamed: R9.1, SD.8 (DATA1)
unnamed: C45.1, U5.4 (BYP)
RESET: C8.1, Q4.3 (C), R16.1, R34.1, RST.2, U1.3 (EN)
RST: C13.2, P2.5, R34.2, R35.2, R44.1
RTS: IC1.19 (RTS), Q4.2 (E), R25.2
RXD/IO44: R29.1, R59.2, U1.36 (RXD0)
TP_INT: P2.4, R36.1, R37.1, R38.2
TXD/IO43: R30.1, U1.37 (TXD0)
USB_D+: R21.1, USB-NATIVE.A6 (D+), USB-NATIVE.B6 (D+)
USB_D-: R20.1, USB-NATIVE.A7 (D-), USB-NATIVE.B7 (D-)
VBAT: BAT.+ (1), C40.1, D11.+, Q6.3 (D), U6.5 (BAT)
VBUS: C6.2, C7.2, D5.A, IC1.8 (VBUS), R11.2, USB-TTL.VBUS1 (VBUS), USB-TTL.VBUS2 (VBUS)
VDD: C26.2, C27.2, C28.2, IC2.P$7 (VDD), IC2.P$8 (VDD), R46.1, R48.1, R55.2, R56.2
VPWR: C35.2, C41.1, D3.C, D11.-, L1.P$1 (1), Q6.2 (S), R39.2, R48.2, U2.6 (IN), U5.1 (VIN), U5.3 (EN)
XN: P5.39
XP: P5.37
YN: P5.40
YP: P5.38

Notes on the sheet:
www.makerfabs.com
Design by Charlin
USB
LEDS
POWER AND FILTERING
USB TO SERIAL CONVERTER
key flash
ESP32-S3 Parallel TFT with Touch 4.3" V3.1
POWER
USB to UART
USB Type C
TF Card
GT911
Closer to IC
Back Light
IO45/IO46: pulldown
IO46: inout &output
Mabee
LCD
MCU
ESP32-S3-WROOM-1
IO47
IO48
Closer to PIN4
HSYNC
VSYNC
DISP
VDD: 2.5-5.5V
0.16V
0.77V
1.4V
LEFT/2 + RIGHT/2
RIGHT
LEFT
0.5V
100K
15dB
Voltage of !SD
LDO&Charger
AO3401

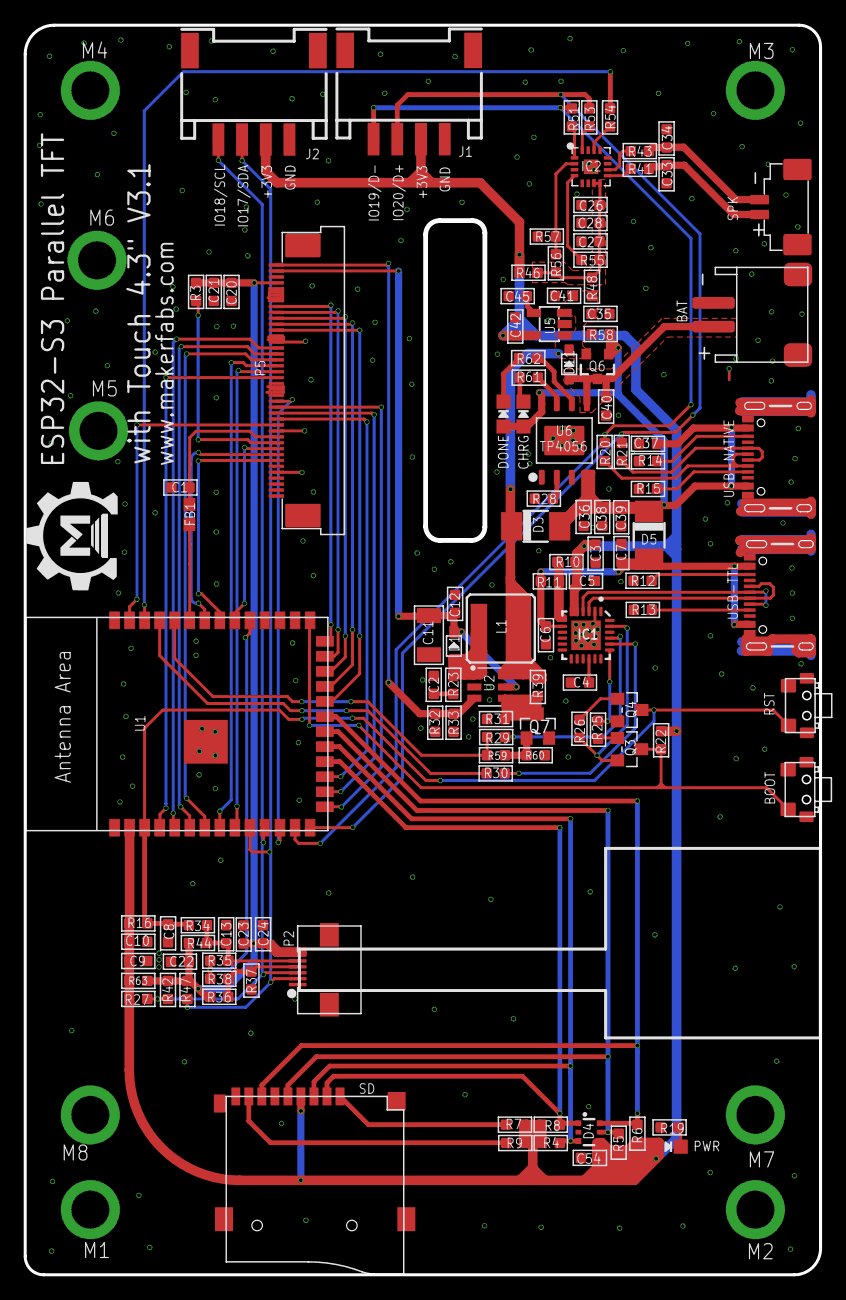
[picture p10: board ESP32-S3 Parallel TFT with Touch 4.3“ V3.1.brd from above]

Board: 2 copper layers, 67.2 x 105.5 mm, 126 parts (0 on the bottom side), 86 nets.

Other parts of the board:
U$1: MAKERFABS_0.3

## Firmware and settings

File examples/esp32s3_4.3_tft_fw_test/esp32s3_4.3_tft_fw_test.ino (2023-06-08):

// Confirm for V3.0

#include <Arduino_GFX_Library.h>
#include <SD.h>
#include <TAMC_GT911.h>
#include <Wire.h>

// jpeg
#include "JpegFunc.h"

// Date and time functions using a PCF8563 RTC connected via I2C and Wire lib
// #include "RTClib.h"

// RTC_PCF8563 rtc;

// char daysOfTheWeek[7][12] = {"Sunday", "Monday", "Tuesday", "Wednesday", "Thursday", "Friday", "Saturday"};

// TFT RTC SD
// V1.3 add RTC
// V1.4 Change BMP to JPEG
// V3.0 delate the RTC

#define I2C_SDA_PIN 17
#define I2C_SCL_PIN 18

#define JPEG_FILENAME_LOGO "/logo.jpg"
#define JPEG_FILENAME_COVER "/cover.jpg"
#define JPEG_FILENAME_COVER_01 "/cover01.jpg"

#define JPEG_FILENAME_01 "/image01.jpg"
#define JPEG_FILENAME_02 "/image02.jpg"
#define JPEG_FILENAME_03 "/image03.jpg"
#define JPEG_FILENAME_04 "/image04.jpg"
#define JPEG_FILENAME_05 "/image05.jpg"

// microSD card
#define SD_SCK 12
#define SD_MISO 13
#define SD_MOSI 11
#define SD_CS 10

#define TOUCH_INT -1
#define TOUCH_RST 38

#define TOUCH_ROTATION ROTATION_NORMAL

/**
#define TOUCH_MAP_X1 480
#define TOUCH_MAP_X2 0
#define TOUCH_MAP_Y1 270
#define TOUCH_MAP_Y2 0
**/

#define TOUCH_MAP_X1 800
#define TOUCH_MAP_X2 0
#define TOUCH_MAP_Y1 480
#define TOUCH_MAP_Y2 0

#define GFX_BL 44
#define TFT_BL GFX_BL

#define PWM_CHANNEL 1
#define PWM_FREQ 5000 // Hz
#define pwm_resolution_bits 10

Arduino_ESP32RGBPanel *bus = new Arduino_ESP32RGBPanel(
    GFX_NOT_DEFINED /* CS */, GFX_NOT_DEFINED /* SCK */, GFX_NOT_DEFINED /* SDA */,
    40 /* DE */, 41 /* VSYNC */, 39 /* HSYNC */, 42 /* PCLK */,
    45 /* R0 */, 48 /* R1 */, 47 /* R2 */, 21 /* R3 */, 14 /* R4 */,
    5 /* G0 */, 6 /* G1 */, 7 /* G2 */, 15 /* G3 */, 16 /* G4 */, 4 /* G5 */,
    8 /* B0 */, 3 /* B1 */, 46 /* B2 */, 9 /* B3 */, 1 /* B4 */
);

// Uncomment for ST7262 IPS LCD 800x480
Arduino_RPi_DPI_RGBPanel *gfx = new Arduino_RPi_DPI_RGBPanel(
    bus,
    800 /* width */, 0 /* hsync_polarity */, 8 /* hsync_front_porch */, 4 /* hsync_pulse_width */, 8 /* hsync_back_porch */,
    480 /* height */, 0 /* vsync_polarity */, 8 /* vsync_front_porch */, 4 /* vsync_pulse_width */, 8 /* vsync_back_porch */,
    1 /* pclk_active_neg */, 16000000 /* prefer_speed */, true /* auto_flush */);

int touch_last_x = 0, touch_last_y = 0;

TAMC_GT911 ts = TAMC_GT911(I2C_SDA_PIN, I2C_SCL_PIN, TOUCH_INT, TOUCH_RST, max(TOUCH_MAP_X1, TOUCH_MAP_X2), max(TOUCH_MAP_Y1, TOUCH_MAP_Y2));

void TouchonInterrupt(void)
{
  // Serial.println("1!");
  ts.isTouched = true;
}

// int ColorArray[]={BLACK,NAVY,DARKGREEN,DARKCYAN,MAROON,PURPLE,OLIVE,LIGHTGREY,DARKGREY,BLUE,GREEN,CYAN,MAGENTA,YELLOW,WHITE,ORANGE,GREENYELLOW,PINK};
int ColorArray[] = {BLACK, BLUE, GREEN, WHITE, RED, ORANGE};

void touch_init(void)
{
  Wire.begin(I2C_SDA_PIN, I2C_SCL_PIN);
  ts.begin();
  ts.setRotation(TOUCH_ROTATION);
}

bool touch_touched(void)
{
#if 0
    ts.read();
    if (ts.isTouched)
    {
        touch_last_x = map(ts.points[0].x, TOUCH_MAP_X1, TOUCH_MAP_X2, 0, 480 - 1);
        touch_last_y = map(ts.points[0].y, TOUCH_MAP_Y1, TOUCH_MAP_Y2, 0, 480 - 1);

        // Serial.print("ox = ");
        // Serial.print(ts.points[0].x);
        // Serial.print(", oy = ");
        // Serial.print(ts.points[0].y);
        // Serial.print(",x = ");
        // Serial.print(touch_last_x);
        // Serial.print(", y = ");
        // Serial.print(touch_last_y);
        // Serial.println();

        return true;
    }
    else
    {
        return false;
    }
#endif
  ts.read();
  if (ts.isTouched)
  {
    touch_last_x = map(ts.points[0].x, TOUCH_MAP_X1, TOUCH_MAP_X2, 0, 800 - 1);
    touch_last_y = map(ts.points[0].y, TOUCH_MAP_Y1, TOUCH_MAP_Y2, 0, 480 - 1);

    for (int i = 0; i < ts.touches; i++)
    {
      Serial.print("Touch ");
      Serial.print(i + 1);
      Serial.print(": ");
      ;
      Serial.print("  x: ");
      Serial.print(ts.points[i].x);
      Serial.print("  y: ");
      Serial.print(ts.points[i].y);
      Serial.print("  size: ");
      Serial.println(ts.points[i].size);
      Serial.println(' ');
      break;
    }
    ts.isTouched = false;
    return true;
  }
  else
  {
    return false;
  }
}

/***********
void pcf8563_init(void)
{
    if (! rtc.begin())
    {
    Serial.println("Couldn't find RTC");
    Serial.flush();

    //while (1) delay(10);
    return;
  }

  if (rtc.lostPower()) {
    Serial.println("RTC is NOT initialized, let's set the time!");
    // When time needs to be set on a new device, or after a power loss, the
    // following line sets the RTC to the date & time this sketch was compiled
    rtc.adjust(DateTime(F(__DATE__), F(__TIME__)));
    // This line sets the RTC with an explicit date & time, for example to set
    // January 21, 2014 at 3am you would call:
    // rtc.adjust(DateTime(2014, 1, 21, 3, 0, 0));
    //
    // Note: allow 2 seconds after inserting battery or applying external power
    // without battery before calling adjust(). This gives the PCF8523's
    // crystal oscillator time to stabilize. If you call adjust() very quickly
    // after the RTC is powered, lostPower() may still return true.
  }

  // When time needs to be re-set on a previously configured device, the
  // following line sets the RTC to the date & time this sketch was compiled
  // rtc.adjust(DateTime(F(__DATE__), F(__TIME__)));
  // This line sets the RTC with an explicit date & time, for example to set
  // January 21, 2014 at 3am you would call:
  // rtc.adjust(DateTime(2014, 1, 21, 3, 0, 0));

  // When the RTC was stopped and stays connected to the battery, it has
  // to be restarted by clearing the STOP bit. Let's do this to ensure
  // the RTC is running.
  rtc.start();
}
***********/
/**
void RTCShow(int num)
{
    DateTime now = rtc.now();

    Serial.print(now.year(), DEC);
    Serial.print('/');
    Serial.print(now.month(), DEC);
    Serial.print('/');
    Serial.print(now.day(), DEC);
    Serial.print(" (");
    Serial.print(daysOfTheWeek[now.dayOfTheWeek()]);
    Serial.print(") ");
    Serial.print(now.hour(), DEC);
    Serial.print(':');
    Serial.print(now.minute(), DEC);
    Serial.print(':');
    Serial.print(now.second(), DEC);
    Serial.println();

    Serial.print(" since midnight 1/1/1970 = ");
    Serial.print(now.unixtime());
    Serial.print("s = ");
    Serial.print(now.unixtime() / 86400L);
    Serial.println("d");

    // calculate a date which is 7 days, 12 hours and 30 seconds into the future
    DateTime future (now + TimeSpan(7,12,30,6));

    Serial.print(" now + 7d + 12h + 30m + 6s: ");
    Serial.print(future.year(), DEC);
    Serial.print('/');
    Serial.print(future.month(), DEC);
    Serial.print('/');
    Serial.print(future.day(), DEC);
    Serial.print(' ');
    Serial.print(future.hour(), DEC);
    Serial.print(':');
    Serial.print(future.minute(), DEC);
    Serial.print(':');
    Serial.print(future.second(), DEC);
    Serial.println();

    gfx->setTextSize(3);
//    if(num) gfx->setTextColor(BLACK);
//    else gfx->setTextColor(WHITE);
    gfx->setCursor(100, 10);
    gfx->print("Time: ");
    gfx->print(String(now.year()));
    gfx->print("/");
    //dtostrf(now.month(),2,0,myS);
    gfx->print(String(now.month()));
    gfx->print("/");
    gfx->print(String(now.day()));
    gfx->print("(");
    gfx->print(daysOfTheWeek[now.dayOfTheWeek()]);
    gfx->print(") ");
    gfx->print(String(now.hour()));
    gfx->print(":");
    gfx->print(String(now.minute()));
    gfx->print(":");
    gfx->print(String(now.second()));
    gfx->print("");
}
**/

// pixel drawing callback
static int jpegDrawCallback(JPEGDRAW *pDraw)
{
  // Serial.printf("Draw pos = %d,%d. size = %d x %d\n", pDraw->x, pDraw->y, pDraw->iWidth, pDraw->iHeight);
  gfx->draw16bitBeRGBBitmap(pDraw->x, pDraw->y, pDraw->pPixels, pDraw->iWidth, pDraw->iHeight);
  return 1;
}

void setup()
{

  Serial.begin(115200);

  pinMode(TFT_BL, OUTPUT);
  digitalWrite(TFT_BL, HIGH);

  pinMode(TOUCH_RST, OUTPUT);
  delay(100);
  digitalWrite(TOUCH_RST, LOW);
  delay(1000);
  digitalWrite(TOUCH_RST, HIGH);
  delay(1000);

  ledcSetup(PWM_CHANNEL, PWM_FREQ, pwm_resolution_bits);
  ledcAttachPin(TFT_BL, PWM_CHANNEL);

  ledcWrite(PWM_CHANNEL, 1023); // output PWM

  // attachInterrupt(TOUCH_INT, TouchonInterrupt, RISING);
  // while (!Serial);
  Serial.println("JPEG Image Viewer");

  digitalWrite(TOUCH_RST, LOW);
  delay(1000);
  digitalWrite(TOUCH_RST, HIGH);
  delay(1000);
  touch_init();
  delay(300);
  // pcf8563_init();

  // Init Display
  gfx->begin();
  gfx->fillScreen(WHITE);
  gfx->setTextSize(4);
  gfx->setTextColor(BLACK);
  gfx->setCursor(300, 50);
  gfx->println(F("Makerfabs"));
  gfx->setCursor(100, 100);
  gfx->println(F("4.3inch TFT with Touch "));

  // ledcWrite(PWM_CHANNEL, 10);
  delay(1000);
  gfx->setCursor(0, 20);
  // gfx->println(F("RED"));
  gfx->fillScreen(RED);
  Serial.println("--RED--");
  delay(1000);

  // ledcWrite(PWM_CHANNEL, 205);
  // gfx->println(F("GREEN"));
  gfx->fillScreen(GREEN);
  Serial.println("--GREEN--");
  delay(1000);

  // ledcWrite(PWM_CHANNEL, 512);
  // gfx->println(F("BLUE"));
  gfx->fillScreen(BLUE);
  Serial.println("--BLUE--");
  delay(1000);

  // ledcWrite(PWM_CHANNEL, 715);
  // gfx->println(F("WHITE"));
  gfx->fillScreen(WHITE);
  Serial.println("--WHITE--");
  delay(1000);

  ledcWrite(PWM_CHANNEL, 0);
  gfx->fillScreen(BLACK);
  Serial.println("--BLACK--");
  delay(1000);
  ledcWrite(PWM_CHANNEL, 1023);
#if 1
  SPI.begin(SD_SCK, SD_MISO, SD_MOSI);
  if (!SD.begin(SD_CS))
  {
    Serial.println(F("ERROR: SD Mount Failed!"));
    // while(1)
    {
      gfx->fillScreen(WHITE);
      gfx->setTextSize(3);
      gfx->setTextColor(RED);
      gfx->setCursor(50, 180);
      gfx->println(F("ERROR: SD Mount Failed!"));
      delay(3000);
    }
  }
  else
  {
    unsigned long start = millis();
    jpegDraw(JPEG_FILENAME_LOGO, jpegDrawCallback, true /* useBigEndian */,
             0 /* x */, 0 /* y */, gfx->width() /* widthLimit */, gfx->height() /* heightLimit */);
    Serial.printf("Time used: %lums\n", millis() - start);
  }

  delay(1000);
  Serial.println("ESP32S3 4.3inch LCD V3.0");

  gfx->fillScreen(WHITE);
  gfx->fillRect(200, 160, 260, 160, BLACK);

  gfx->setTextSize(4);
  gfx->setTextColor(WHITE);
  gfx->setCursor(200 + 20, 180);
  gfx->println("3 * POINTS ");
  gfx->setCursor(200 + 20, 220);
  gfx->println("TOUCH TO");
  gfx->setCursor(200 + 20, 260);
  gfx->println("CONTINUE");

  jpegDraw(JPEG_FILENAME_COVER_01, jpegDrawCallback, true /* useBigEndian */,
           0 /* x */, 0 /* y */, gfx->width() /* widthLimit */, gfx->height() /* heightLimit */);
  delay(500);

  while (1)
  {
    ts.read();
    if (ts.isTouched)
    {
      for (int i = 0; i < ts.touches; i++)
      {
        // gfx->fillScreen(WHITE);
        int temp = random(0, 6);
        gfx->fillScreen(ColorArray[temp]);

        gfx->setTextSize(4);
        // if(num) gfx->setTextColor(BLACK);
        // else
        if (temp == 4)
          gfx->setTextColor(WHITE);
        else
          gfx->setTextColor(RED);
        gfx->setCursor(320, 400);
        gfx->print("X: ");
        gfx->println(String(ts.points[i].x));
        gfx->setCursor(320, 440);
        gfx->print("Y: ");
        gfx->println(String(ts.points[i].y));

        // RTCShow(0);

        Serial.print("Touch ");
        Serial.print(i + 1);
        Serial.print(": ");
        ;
        Serial.print("  x: ");
        Serial.print(ts.points[i].x);
        Serial.print("  y: ");
        Serial.print(ts.points[i].y);
        Serial.print("  size: ");
        Serial.println(ts.points[i].size);
        Serial.println(' ');
      }

      ts.isTouched = false;
      if (ts.touches > 2)
        break;
    }
    delay(100);
  }
#endif
}

void loop()
{
  /**
  gfx->fillScreen(GREEN);
  Serial.println("GREEN");
  RTCShow(0);
  delay(1000);
  gfx->fillScreen(BLUE);
  Serial.println("BLUE");
  RTCShow(0);
  delay(1000);
  gfx->fillScreen(WHITE);
  Serial.println("WHITE");
  RTCShow(1);
  delay(1000);
  gfx->fillScreen(YELLOW);
  Serial.println("YELLOW");
  RTCShow(1);
  delay(1000);
  ***/

  int w = gfx->width();
  int h = gfx->height();
#if 0
  unsigned long start = millis();
  jpegDraw(JPEG_FILENAME_01, jpegDrawCallback, true /* useBigEndian */,
           random(w * 2) - w /* x */,
           random(h * 2) - h /* y */,
           w /* widthLimit */, h /* heightLimit */);
  Serial.printf("Time used: %lums\n", millis() - start);
  RTCShow(random(0,2));
  delay(1000);
#endif

  unsigned long start = millis();
  jpegDraw(JPEG_FILENAME_01, jpegDrawCallback, true /* useBigEndian */,
           0 /* x */, 0 /* y */, gfx->width() /* widthLimit */, gfx->height() /* heightLimit */);
  Serial.printf("Time used: %lums\n", millis() - start);
  delay(1000);
  start = millis();
  jpegDraw(JPEG_FILENAME_02, jpegDrawCallback, true /* useBigEndian */,
           0 /* x */, 0 /* y */, gfx->width() /* widthLimit */, gfx->height() /* heightLimit */);
  Serial.printf("Time used: %lums\n", millis() - start);
  delay(1000);
  start = millis();
  jpegDraw(JPEG_FILENAME_03, jpegDrawCallback, true /* useBigEndian */,
           0 /* x */, 0 /* y */, gfx->width() /* widthLimit */, gfx->height() /* heightLimit */);
  Serial.printf("Time used: %lums\n", millis() - start);
  delay(1000);
  start = millis();
  jpegDraw(JPEG_FILENAME_04, jpegDrawCallback, true /* useBigEndian */,
           0 /* x */, 0 /* y */, gfx->width() /* widthLimit */, gfx->height() /* heightLimit */);
  Serial.printf("Time used: %lums\n", millis() - start);
  delay(1000);
  jpegDraw(JPEG_FILENAME_05, jpegDrawCallback, true /* useBigEndian */,
           0 /* x */, 0 /* y */, gfx->width() /* widthLimit */, gfx->height() /* heightLimit */);
  Serial.printf("Time used: %lums\n", millis() - start);
  delay(1000);
}

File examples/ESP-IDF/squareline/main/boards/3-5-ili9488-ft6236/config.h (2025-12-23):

#ifndef _BOARD_CONFIG_H_
#define _BOARD_CONFIG_H_

#include <driver/gpio.h>

#define AUDIO_INPUT_SAMPLE_RATE  16000
#define AUDIO_OUTPUT_SAMPLE_RATE 16000


#define SPI2_MOSI_PIN   GPIO_NUM_2
#define SPI2_MISO_PIN   GPIO_NUM_41
#define SPI2_CLK_PIN    GPIO_NUM_42

#define SPI3_MOSI_PIN   GPIO_NUM_13
#define SPI3_MISO_PIN   GPIO_NUM_12
#define SPI3_CLK_PIN    GPIO_NUM_14


// 如果使用 Duplex I2S 模式，请注释下面一行
// #define AUDIO_I2S_METHOD_SIMPLEX

#ifdef AUDIO_I2S_METHOD_SIMPLEX

#define AUDIO_I2S_MIC_GPIO_WS       GPIO_NUM_2
#define AUDIO_I2S_MIC_GPIO_SCK      GPIO_NUM_42
#define AUDIO_I2S_MIC_GPIO_DIN      GPIO_NUM_41
#define AUDIO_I2S_SPK_GPIO_DOUT     GPIO_NUM_19
#define AUDIO_I2S_SPK_GPIO_BCLK     GPIO_NUM_20
#define AUDIO_I2S_SPK_GPIO_LRCK     GPIO_NUM_1

#else

#define AUDIO_I2S_GPIO_WS           GPIO_NUM_43
#define AUDIO_I2S_GPIO_BCLK         GPIO_NUM_44
#define AUDIO_I2S_GPIO_DIN          GPIO_NUM_2
#define AUDIO_I2S_GPIO_DOUT         GPIO_NUM_19

#endif


#define BUILTIN_LED_GPIO            GPIO_NUM_NC
#define BOOT_BUTTON_GPIO            GPIO_NUM_0
#define TOUCH_BUTTON_GPIO           GPIO_NUM_NC
#define VOLUME_UP_BUTTON_GPIO       GPIO_NUM_NC
#define VOLUME_DOWN_BUTTON_GPIO     GPIO_NUM_NC

#if CONFIG_3_5_IlI9488_SPI_FT6236
#define DISPLAY_BACKLIGHT_PIN       GPIO_NUM_48
#else
#define DISPLAY_BACKLIGHT_PIN       GPIO_NUM_45
#endif
#define DISPLAY_MOSI_PIN            SPI3_MOSI_PIN
#define DISPLAY_MISO_PIN            SPI3_MISO_PIN
#define DISPLAY_CLK_PIN             SPI3_CLK_PIN
#define DISPLAY_DC_PIN              GPIO_NUM_21
#define DISPLAY_RST_PIN             GPIO_NUM_NC
#define DISPLAY_CS_PIN              GPIO_NUM_15
#define DISPLAY_RD_PIN              GPIO_NUM_48

#define EXAMPLE_LCD_IO_SPI_CS       GPIO_NUM_45
#define EXAMPLE_LCD_IO_SPI_SCK      GPIO_NUM_39
#define EXAMPLE_LCD_IO_SPI_SDO      GPIO_NUM_40
#define EXAMPLE_LCD_IO_RGB_DE       GPIO_NUM_7
#define EXAMPLE_LCD_IO_RGB_PCLK     GPIO_NUM_6
#define EXAMPLE_LCD_IO_RGB_VSYNC    GPIO_NUM_4
#define EXAMPLE_LCD_IO_RGB_HSYNC    GPIO_NUM_5
#define EXAMPLE_LCD_IO_RGB_DISP 
#define EXAMPLE_LCD_IO_RGB_RESET    GPIO_NUM_NC

#define EXAMPLE_LCD_IO_DATA0        GPIO_NUM_47
#define EXAMPLE_LCD_IO_DATA1        GPIO_NUM_21
#define EXAMPLE_LCD_IO_DATA2        GPIO_NUM_14
#define EXAMPLE_LCD_IO_DATA3        GPIO_NUM_13
#define EXAMPLE_LCD_IO_DATA4        GPIO_NUM_12
#define EXAMPLE_LCD_IO_DATA5        GPIO_NUM_11
#define EXAMPLE_LCD_IO_DATA6        GPIO_NUM_10
#define EXAMPLE_LCD_IO_DATA7        GPIO_NUM_9
#define EXAMPLE_LCD_IO_DATA8        GPIO_NUM_3
#define EXAMPLE_LCD_IO_DATA9        GPIO_NUM_8
#define EXAMPLE_LCD_IO_DATA10       GPIO_NUM_16
#define EXAMPLE_LCD_IO_DATA11       GPIO_NUM_15
#define EXAMPLE_LCD_IO_DATA12       GPIO_NUM_7
#define EXAMPLE_LCD_IO_DATA13       GPIO_NUM_6
#define EXAMPLE_LCD_IO_DATA14       GPIO_NUM_5
#define EXAMPLE_LCD_IO_DATA15       GPIO_NUM_4




#define TOUCH_SDA_PIN               GPIO_NUM_38
#define TOUCH_SCL_PIN               GPIO_NUM_39
#define TOUCH_INT_PIN               GPIO_NUM_NC
#define TOUCH_RST_PIN               GPIO_NUM_NC

#define SDCARD_MOUNT_POINT          "/sdcard"
#define SDCARD_CS_PIN               GPIO_NUM_1
#define SDCARD_MISO_PIN             SPI2_MISO_PIN
#define SDCARD_MOSI_PIN             SPI2_MOSI_PIN
#define SDCARD_CLK_PIN              SPI2_CLK_PIN





#define DISPLAY_WIDTH                   320
#define DISPLAY_HEIGHT                  480
#define DISPLAY_MIRROR_X                false
#define DISPLAY_MIRROR_Y                false
#define DISPLAY_SWAP_XY                 false
#define DISPLAY_INVERT_COLOR            true
#define DISPLAY_RGB_ORDER               LCD_RGB_ELEMENT_ORDER_BGR
#define DISPLAY_OFFSET_X                0
#define DISPLAY_OFFSET_Y                0
#define DISPLAY_BACKLIGHT_OUTPUT_INVERT false
#define DISPLAY_SPI_MODE                0



// A MCP Test: Control a lamp
#define LAMP_GPIO GPIO_NUM_18

#endif // _BOARD_CONFIG_H_

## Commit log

2022-12-10 add hardware and images for display
    [ESP32-S3 Parallel TFT with Touch 4.3“ V1.1.brd, ESP32-S3 Parallel TFT with Touch 4.3“ V1.1.sch]
2023-01-03 Add I2C wire scan and backlight controll
2023-01-10 V1.3 Pin Change
2023-01-10 V1.3 Pin change and code fix
    [config.h, hid_keyboard.ino]
2023-01-11 V1.3 hardware update
    [ESP32-S3 Parallel TFT with Touch 4.3“ V1.3.brd, ESP32-S3 Parallel TFT with Touch 4.3“ V1.3.sch]
2023-04-15 V2.0 Hardware
    [ESP32-S3 Parallel TFT with Touch 4.3“ V2.0.brd, ESP32-S3 Parallel TFT with Touch 4.3“ V2.0.sch]
2023-07-11 Update hardware
    [ESP32-S3 Parallel TFT with Touch 4.3“ V3.1.brd, ESP32-S3 Parallel TFT with Touch 4.3“ V3.1.sch]
2025-12-23 add esp-idf example
    [code-format.cfg, jconfig.txt, partitions.csv]
2025-12-29 add example for use squreline and idf
    [jconfig.txt, partitions.csv]

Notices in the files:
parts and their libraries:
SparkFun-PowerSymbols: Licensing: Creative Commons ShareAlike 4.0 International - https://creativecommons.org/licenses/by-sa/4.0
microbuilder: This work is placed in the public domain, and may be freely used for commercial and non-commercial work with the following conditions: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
